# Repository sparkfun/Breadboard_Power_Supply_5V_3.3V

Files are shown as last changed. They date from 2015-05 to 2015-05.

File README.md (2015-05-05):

SparkFun Breadboard Power Supply 5V/3.3V
========================================

SparkFun Breadboard Power Supply 5V/3.3V

[*SparkFun Breadboard Power Supply 5V/3.3V (PRT-00114)*](https://www.sparkfun.com/products/114)

ere is a very simple breadboard power supply kit that takes power from a DC wall wart and outputs a selectable 5V or 3.3V regulated voltage.

Repository Contents
-------------------

* **/Hardware** - Eagle design files (.brd, .sch)
* **/Production** - Production panel files (.brd)

Documentation
--------------
* **[Hookup Guide](https://www.sparkfun.com/tutorials/297)** - Basic hookup guide for the Breadboard Power Supply.
* **[SparkFun Fritzing repo](https://github.com/sparkfun/Fritzing_Parts)** - Fritzing diagrams for SparkFun products.
* **[SparkFun 3D Model repo](https://github.com/sparkfun/3D_Models)** - 3D models of SparkFun products. 

License Information
-------------------
This product is _**open source**_! 

The **hardware** is released under [Creative Commons ShareAlike 4.0 International](https://creativecommons.org/licenses/by-sa/4.0/).

Please use, reuse, and modify these files as you see fit. Please maintain attribution to SparkFun Electronics and release anything derivative under the same license.

Distributed as-is; no warranty is given.

- Your friends at SparkFun.

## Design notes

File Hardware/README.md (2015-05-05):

SparkFun <PRODUCT NAME> Design Files
=====================================

The .sch and .brd files hare are Eagle CAD schematic and PCB design files from SparkFun Electronics.
A freeware version of Eagle can be found [here](http://www.cadsoftusa.com/download-eagle/freeware/). 

License
---------
This product is open source! 
The hardware is released under [Creative Commons ShareAlike 4.0 International](https://creativecommons.org/licenses/by-sa/4.0/).

Please use, reuse, and modify these files as you see fit. Please maintain attribution to SparkFun Electronics and release anything derivative under the same license.

Distributed as-is; no warranty is given.

- Your friends at SparkFun.

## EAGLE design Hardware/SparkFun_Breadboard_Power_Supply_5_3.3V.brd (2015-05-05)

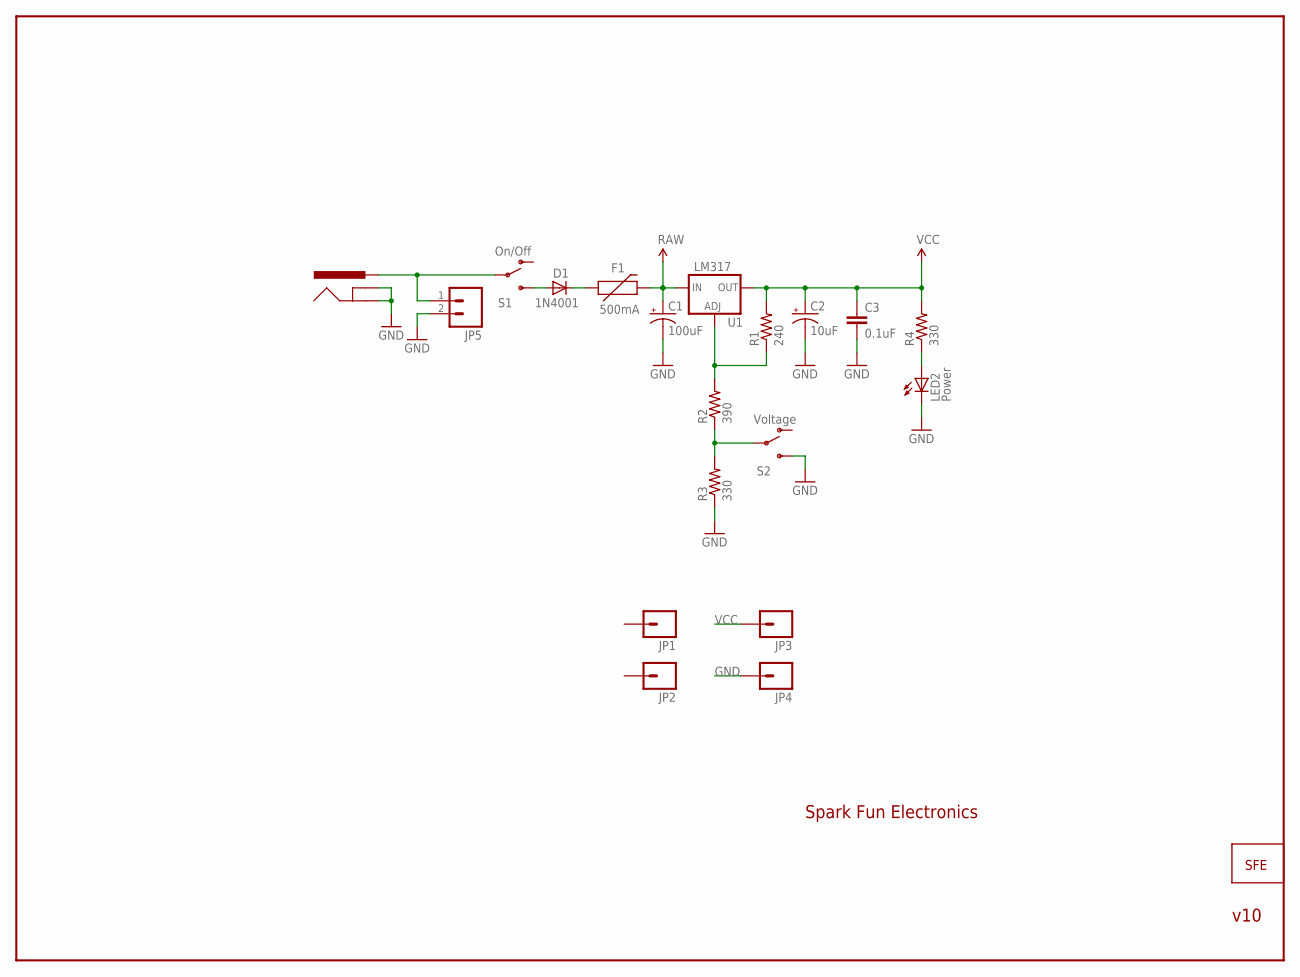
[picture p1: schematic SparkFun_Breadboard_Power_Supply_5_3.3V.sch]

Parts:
C1: 100uF; CPOL-RADIAL-100UF-25V
C2: 10uF; CPOL-RADIAL-10UF-25V
C3: 0.1uF; CAP-PTH-SMALL2
D1: 1N4001; DIODE-0.4
F1: 500mA; PTC
J1: POWER_JACKPTH; POWER_JACK_PTH
JP1, JP2, JP3, JP4: M01PTH; 1X01
JP5: M02PTH; 1X02
LED2: Power; LED5MM
R1: 240; AXIAL-0.3
R2: 390; AXIAL-0.3
R3, R4: 330; AXIAL-0.3
S1: On/Off; SWITCH-SPST
S2: Voltage; SWITCH-SPST
U1: LM317; TO220-ADJ
U$1: LOGO-SFESK; SFE-LOGO-FLAME

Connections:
GND: C1.2 (-), C2.2 (-), C3.2, J1.GND, J1.GNDBREAK, JP4.1, JP5.2, LED2.K (C), R3.P$1 (1), S2.3 (S)
unnamed: D1.C, F1.P$1 (1)
unnamed: D1.A, S1.3 (S)
unnamed: J1.PWR, JP5.1, S1.2
unnamed: R2.P$1 (1), R3.P$2 (2), S2.2
unnamed: R1.P$1 (1), R2.P$2 (2), U1.ADJ
unnamed: LED2.A, R4.P$1 (1)
RAW: C1.1 (+), F1.P$2 (2), U1.IN
VCC: C2.1 (+), C3.1, JP3.1, R1.P$2 (2), R4.P$2 (2), U1.OUT

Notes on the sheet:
Spark Fun Electronics
v10

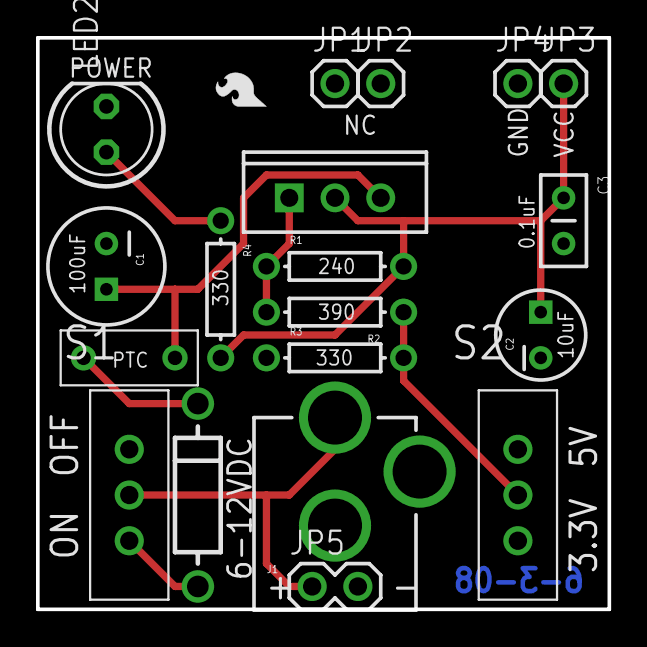
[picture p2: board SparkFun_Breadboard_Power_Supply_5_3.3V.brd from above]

Board: 2 copper layers, 31.8 x 31.8 mm, 20 parts (0 on the bottom side), 9 nets.
